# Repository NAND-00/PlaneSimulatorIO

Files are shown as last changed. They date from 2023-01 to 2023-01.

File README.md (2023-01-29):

# PlaneSimulatorIO
Plug'n'play I/O board for connecting flight simulator controls to the PC/MAC via USB with extended X-Plane support.

The I/O board is a USB-HID device designed to connect your flight simulator controls to the flight simulator program. It supports up to 32 digital inputs (buttons or switches), two motorized trims with servo indicators, flaps lever with a servo indicator, fuel quadrant, yoke, pedals and a gear switch with three LED indicators.

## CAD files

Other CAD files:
XPlane_plugin_VSproject/Release/64/Hello-World-SDK-3.obj
XPlane_plugin_VSproject/Release/64/CockpitIOPlugin.obj
XPlane_plugin_VSproject/Release/64/hid.obj

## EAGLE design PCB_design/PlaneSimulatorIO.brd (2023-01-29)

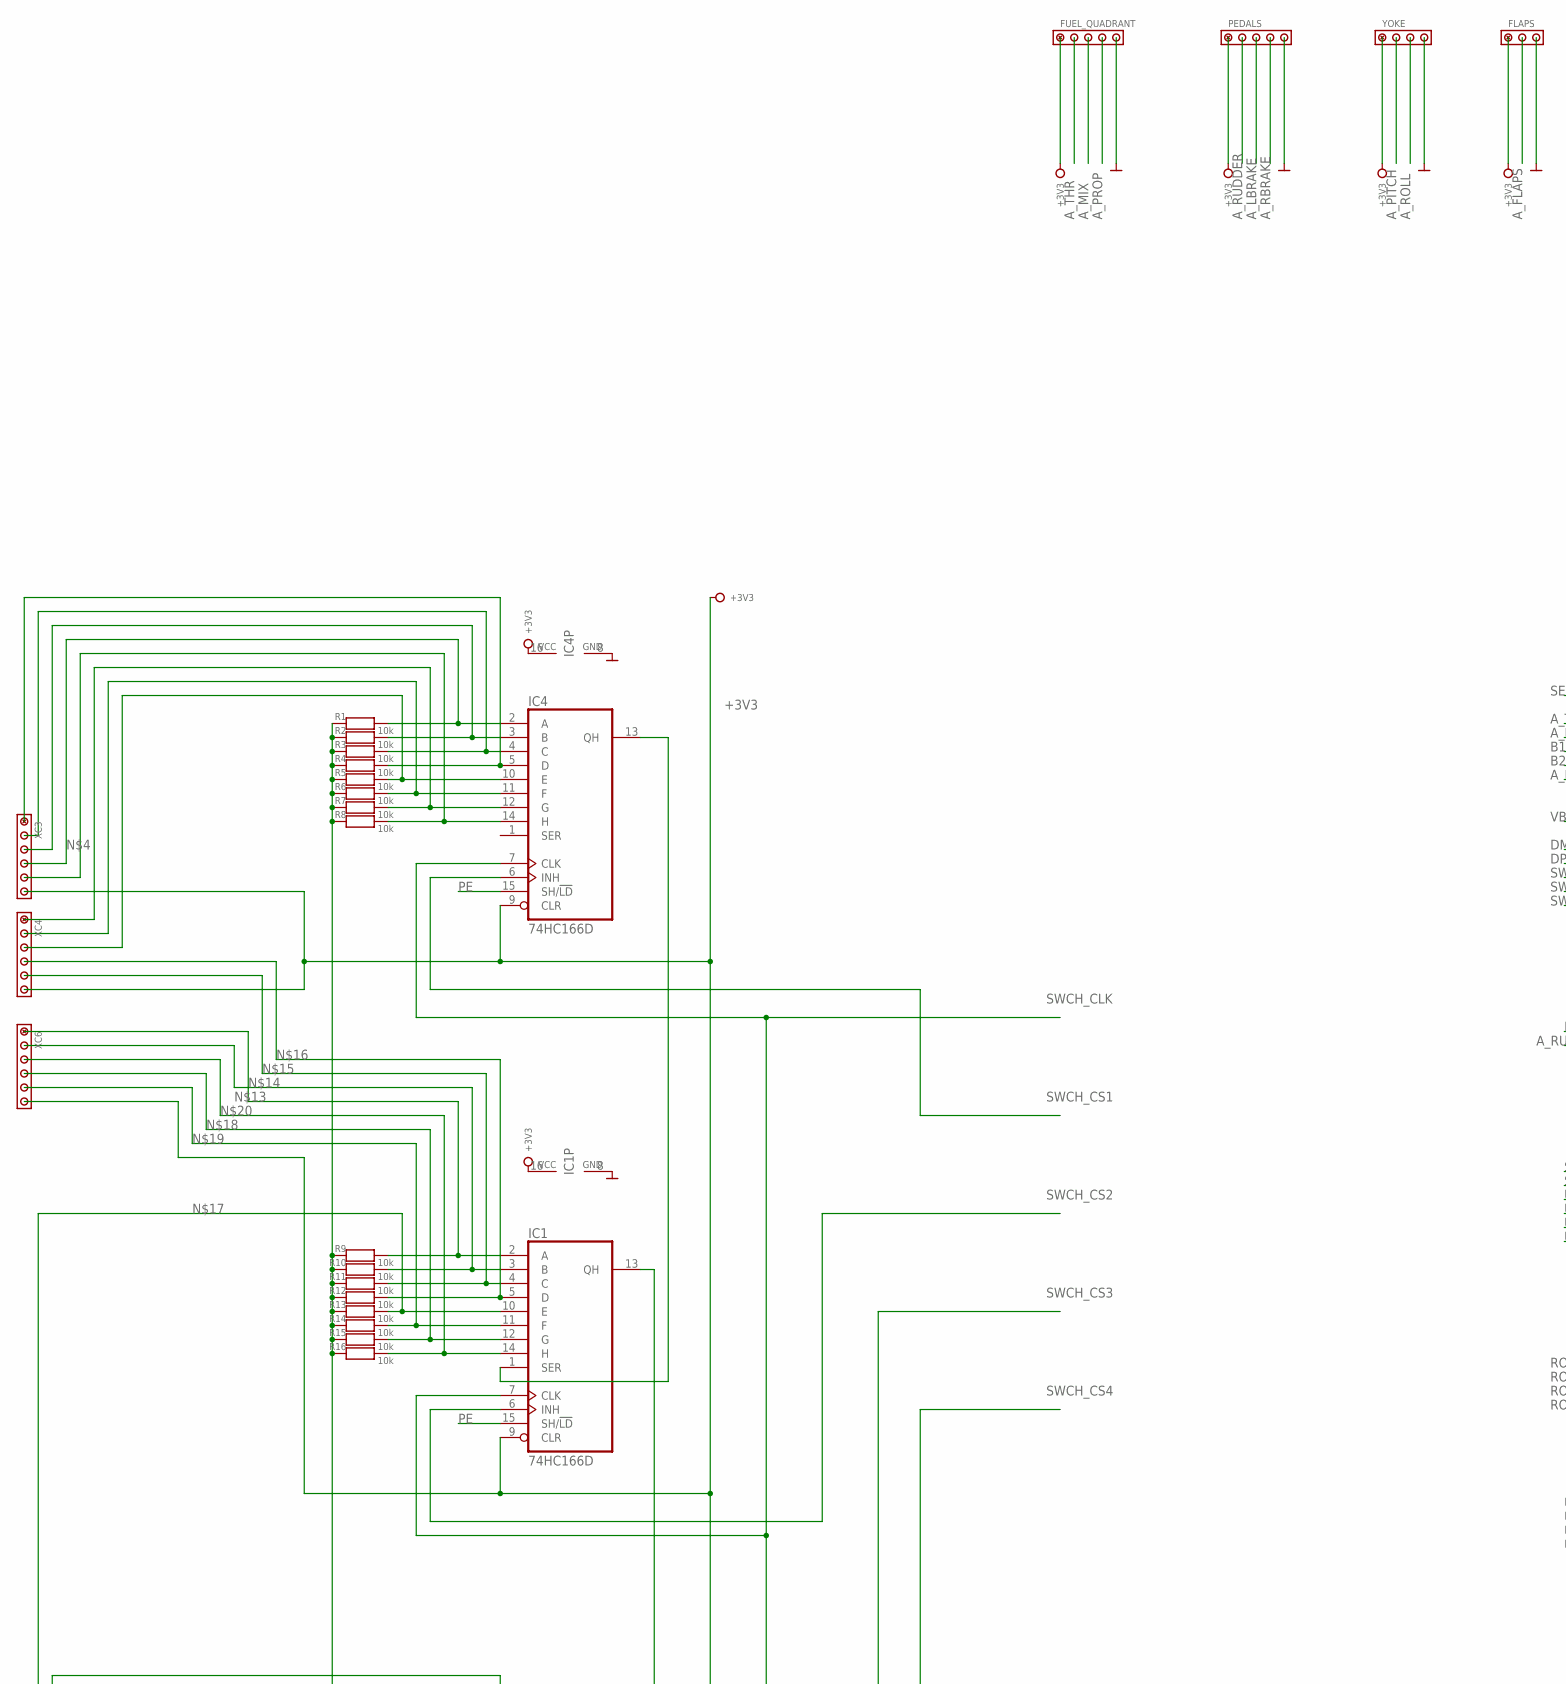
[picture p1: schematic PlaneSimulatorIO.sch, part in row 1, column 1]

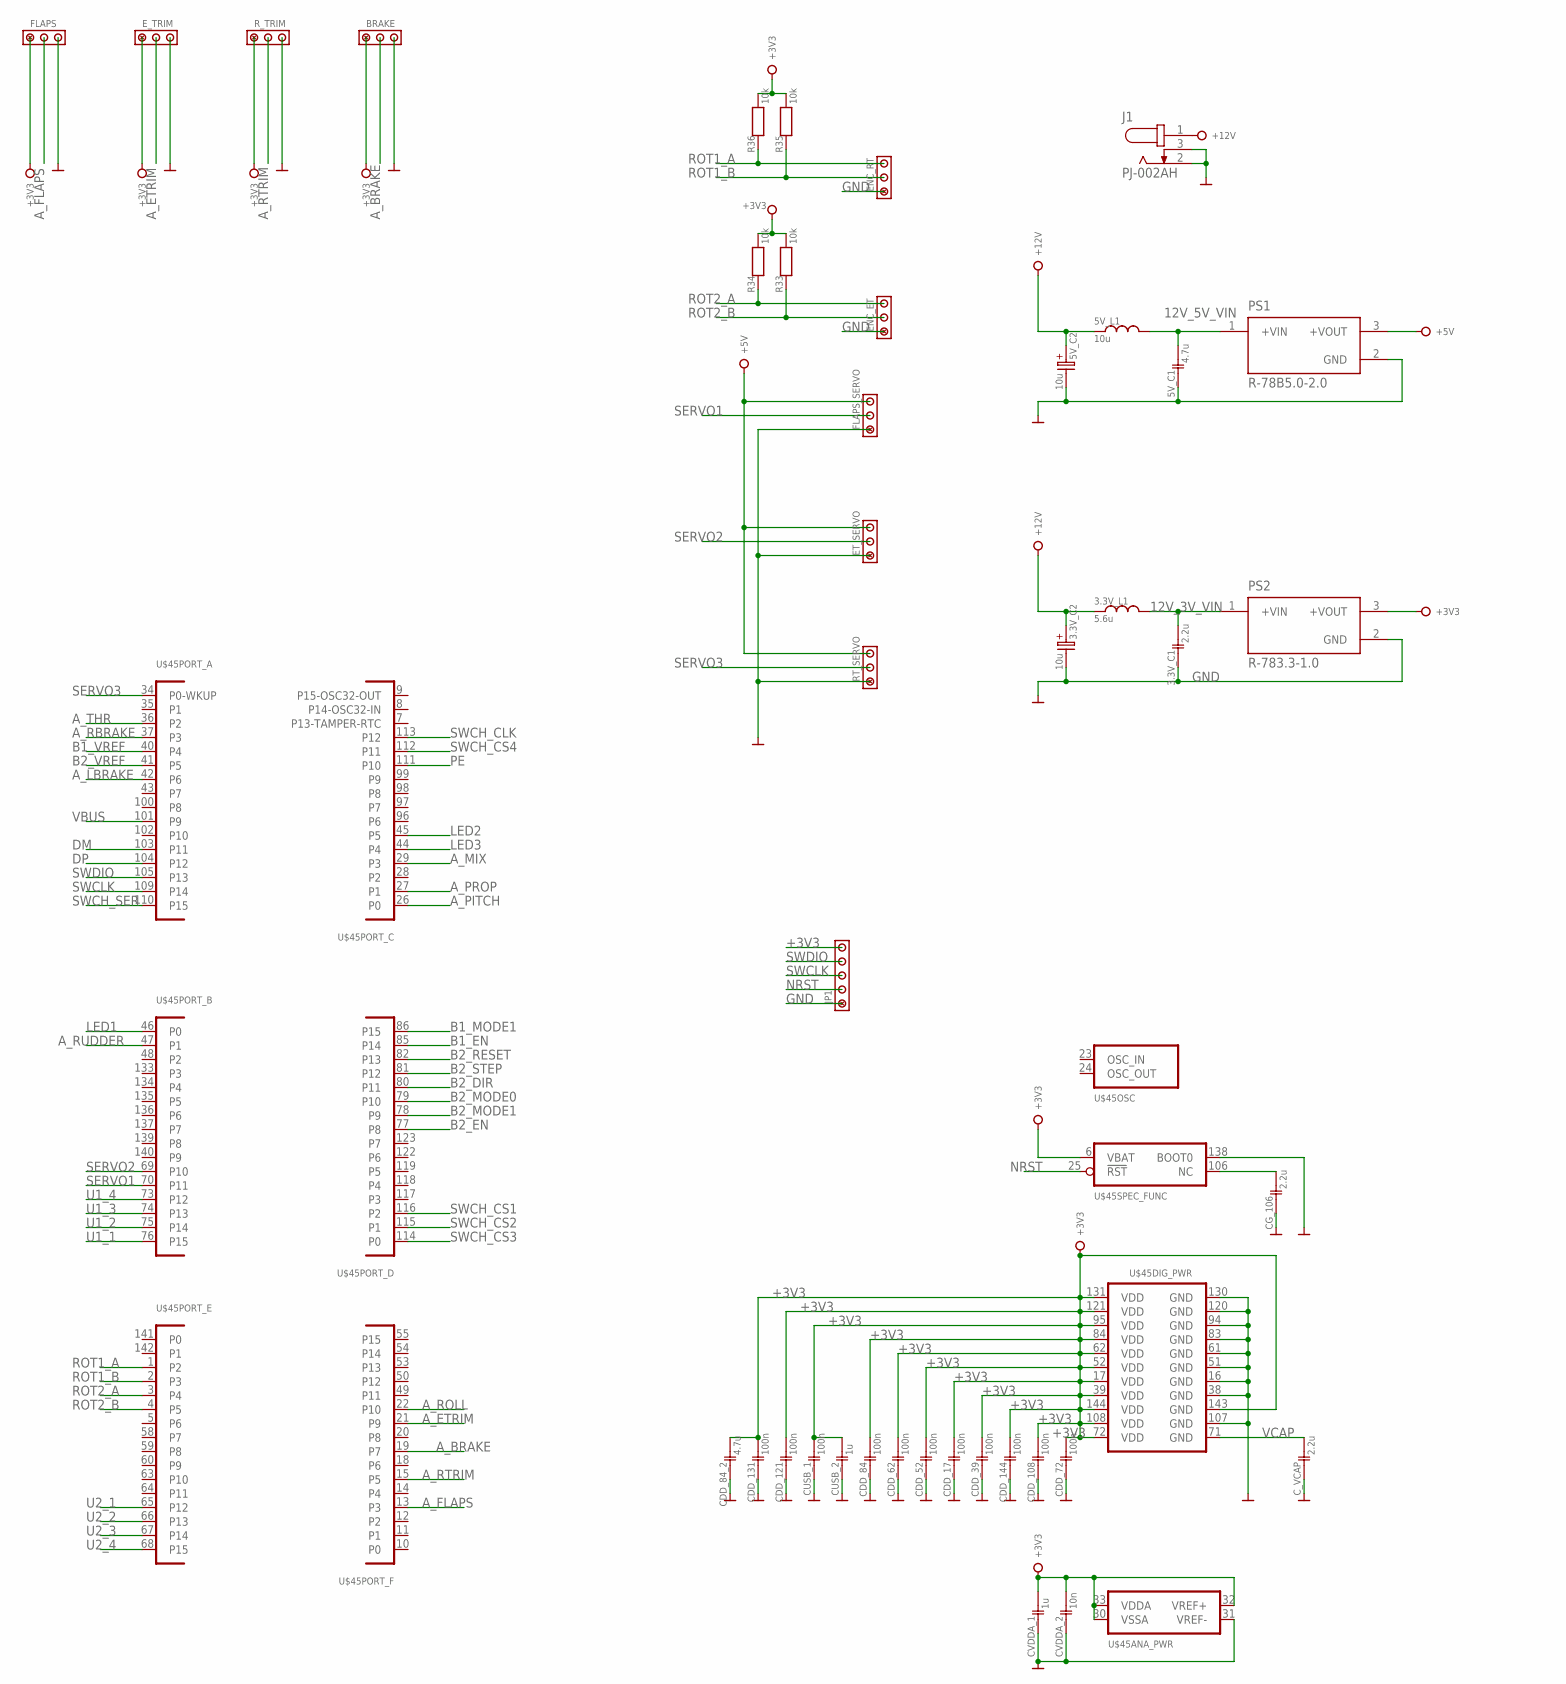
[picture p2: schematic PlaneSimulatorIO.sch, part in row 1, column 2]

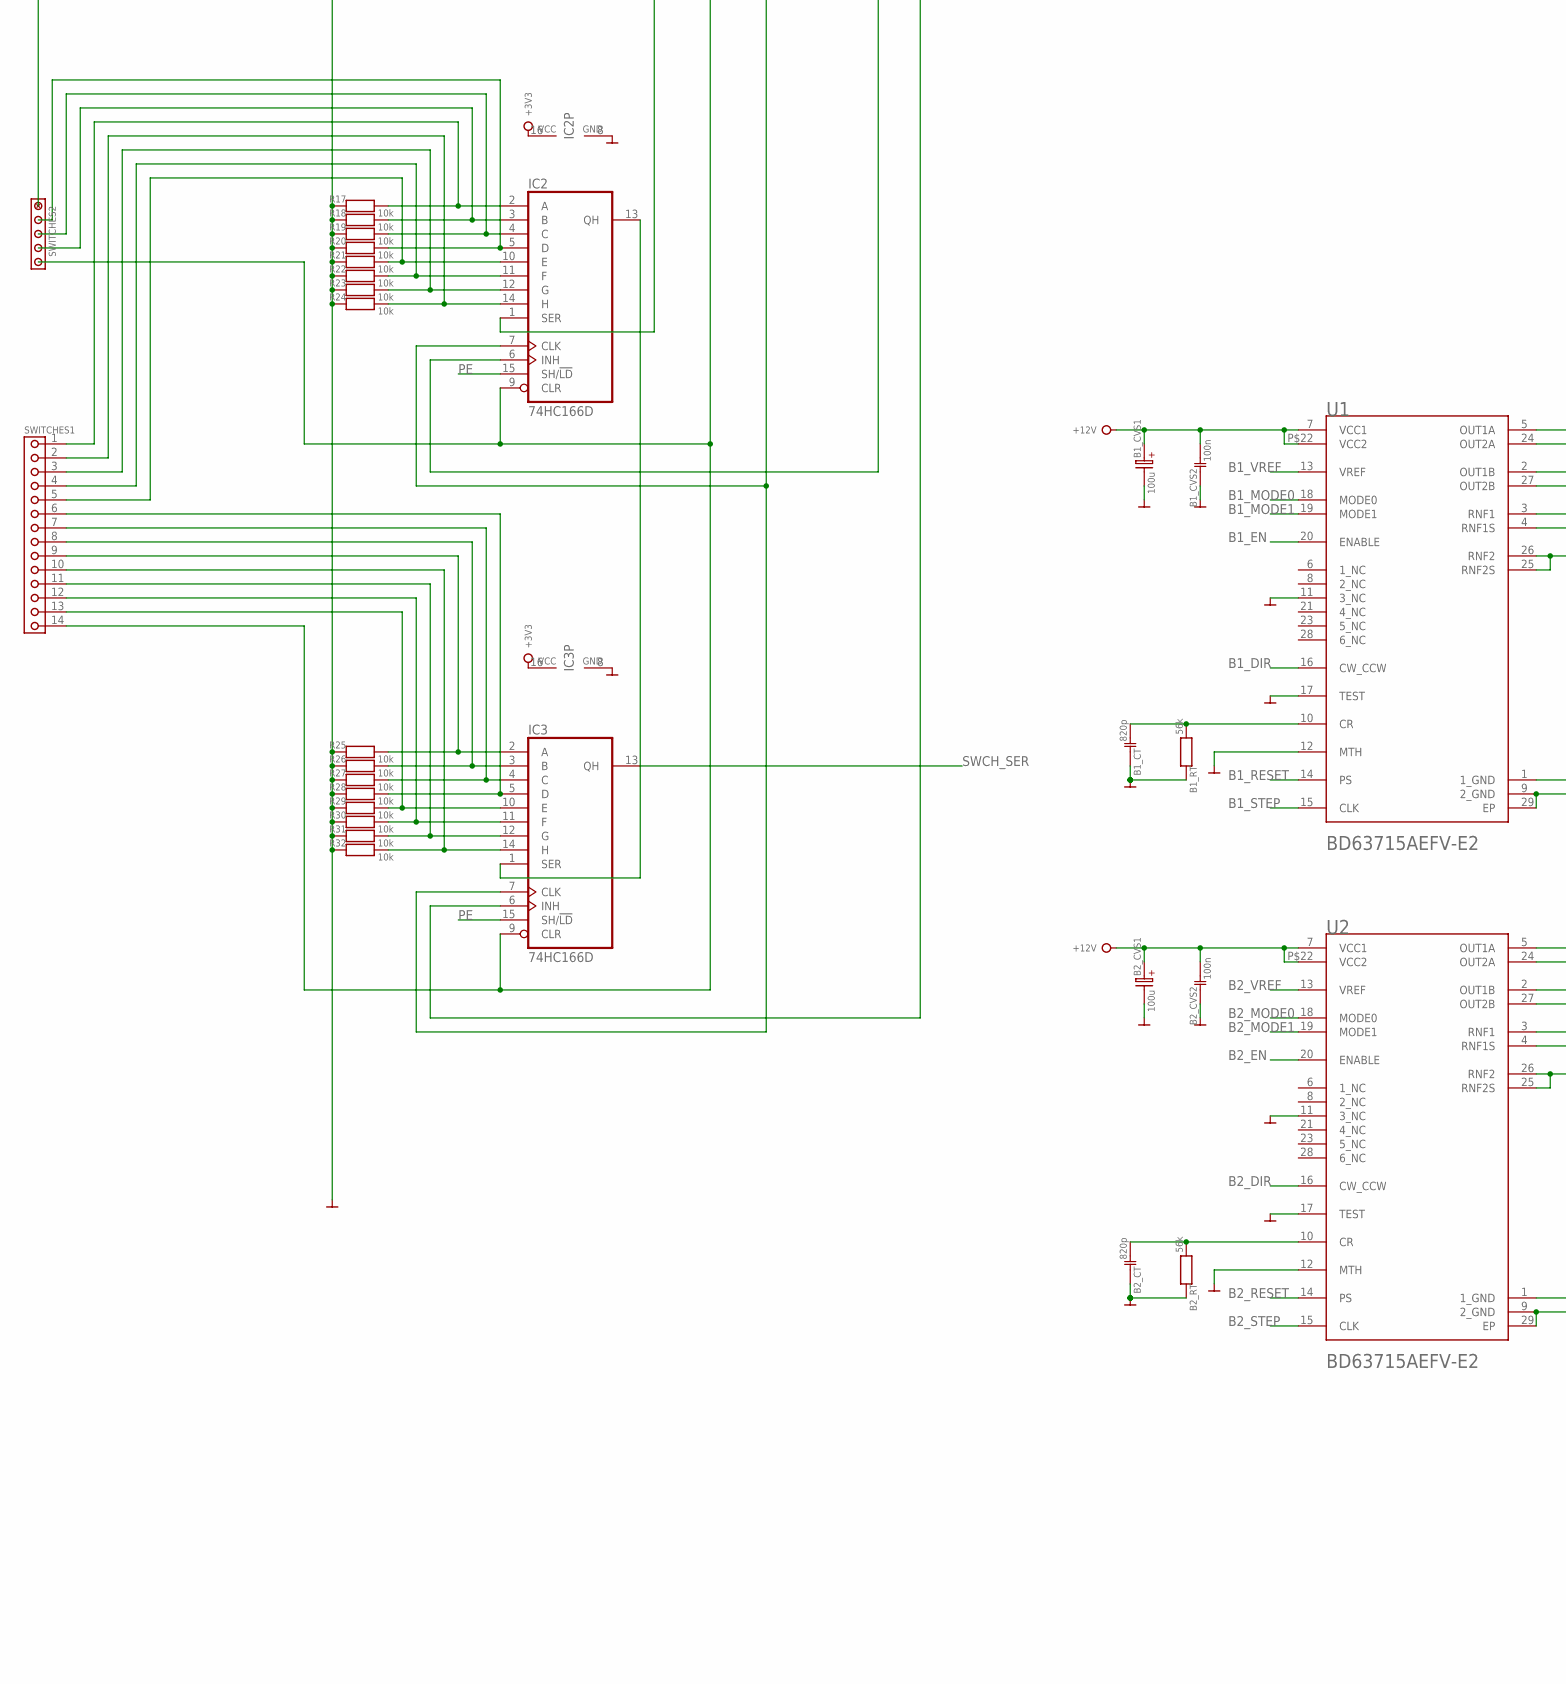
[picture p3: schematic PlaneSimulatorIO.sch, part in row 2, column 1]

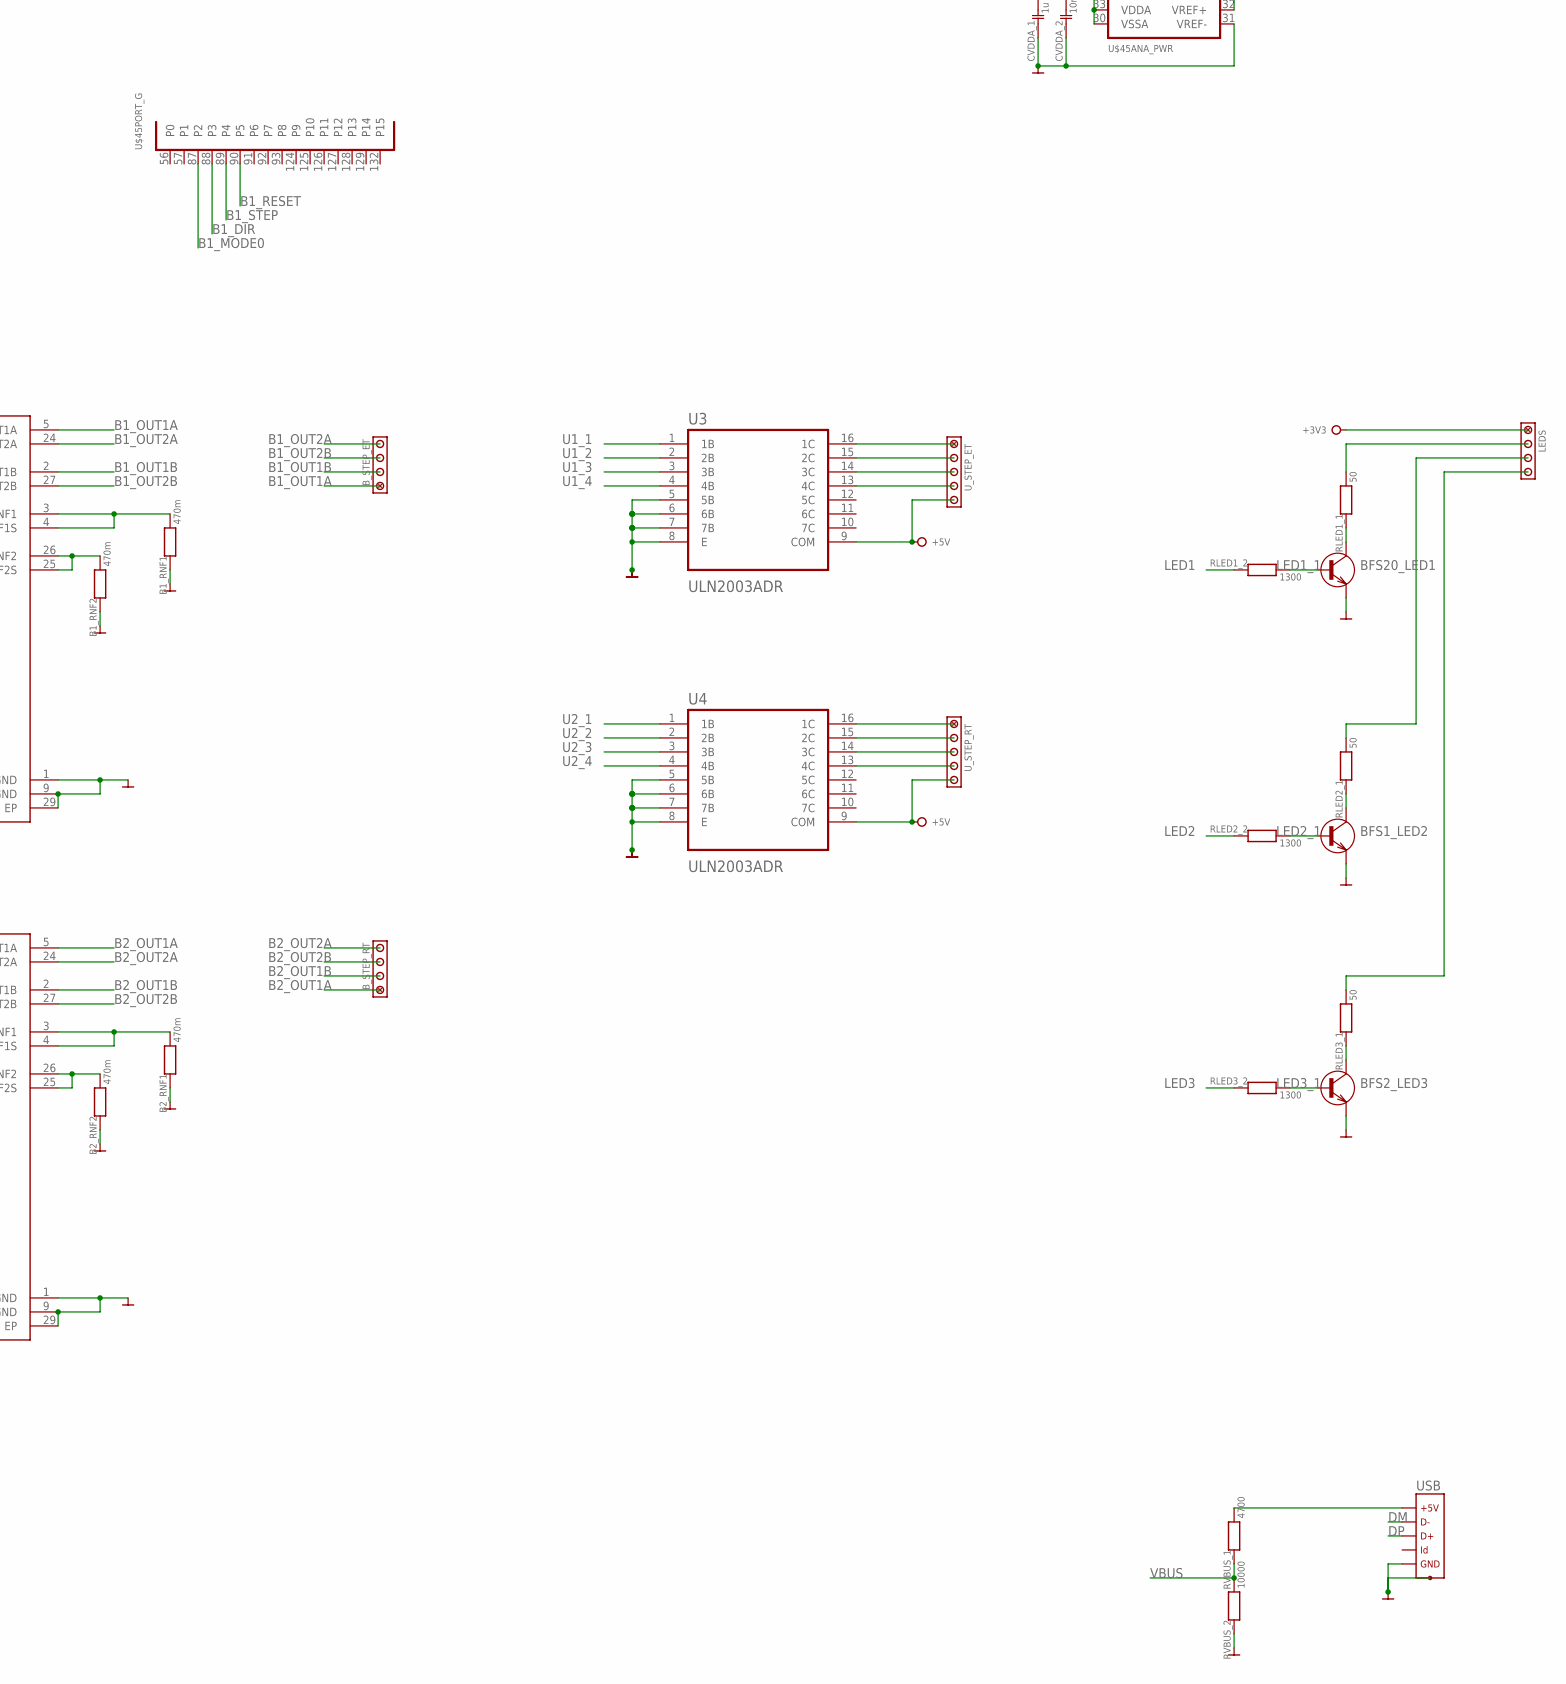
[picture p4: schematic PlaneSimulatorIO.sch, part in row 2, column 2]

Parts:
3.3V_C1: 2.2u; 1206
3.3V_C2, 5V_C2: 10u; EC10-5
3.3V_L1: 5.6u; 0805
5V_C1: 4.7u; 1206
5V_L1: 10u; DR74
B1_CT, B2_CT: 820p; 0603
B1_CVS1, B2_CVS1: 100u; EC10-5
B1_CVS2, B2_CVS2: 100n; 0603
B1_RNF1, B1_RNF2, B2_RNF1, B2_RNF2: 470m; 1206
B1_RT, B2_RT: 56k; 0603
BFS1_LED2, BFS2_LED3, BFS20_LED1: #NPNSOT23-3L; SOT23-3L
BRAKE: MCV/03; MCV3
B_STEP_ET: MCV/04; MCV4
B_STEP_RT: MCV/04; MCV4
CDD_17, CDD_39, CDD_52, CDD_62, CDD_72, CDD_84, CDD_108, CDD_121, CDD_131, CDD_144: 100n; 0603
CDD_84_2: 4.7u; 0603
CG_106: 2.2u; 0603
CUSB_1: 100n; 0603
CUSB_2: 1u; 0603
CVDDA_1: 1u; 0603
CVDDA_2: 10n; 0603
C_VCAP: 2.2u; 0603
ENC_ET: MCV/03; MCV3
ENC_RT: MCV/03; MCV3
ET_SERVO: MCV/03; MCV3
E_TRIM: MCV/03; MCV3
FLAPS: MCV/03; MCV3
FLAPS_SERVO: MCV/03; MCV3
FUEL_QUADRANT: MCV/05; MCV5
IC1, IC2, IC3, IC4: 74HC166D; SO16
J1: PJ-002AH; CUI_PJ-002AH
JP1: JP_05JP_05-2.54; JP_05
LEDS: MCV/04; MCV4
PEDALS: MCV/05; MCV5
PS1: R-78B5.0-2.0; CONV_R-78B5.0-2.0
PS2: R-783.3-1.0; CONV_R-783.3-1.0
R1, R2, R3, R4, R5, R6, R7, R8, R9, R10, R11, R12, R13, R14, R15, R16, R17, R18, R19, R20, R21, R22, R23, R24, R25, R26, R27, R28, R29, R30, R31, R32, R33, R34, R35, R36: 10k; 0603
RLED1_1, RLED2_1, RLED3_1: 50; 0603
RLED1_2, RLED2_2, RLED3_2: 1300; 0603
RT_SERVO: MCV/03; MCV3
RVBUS_1: 4700; 0603
RVBUS_2: 10000; 0603
R_TRIM: MCV/03; MCV3
SWITCHES1: 14MCV3.81; MCV14
SWITCHES2: MCV/05; MCV5
U1, U2: ROHM_BD63715AEFV-E2ROHM_BD63715AEFV-E2_0_3; ROHM_BD63715AEFV-E2_3
U3, U4: ULN2003ADR; SOIC127P600X175-16N
U$45: STM32F103ZE; SQFP-S-20X20-144
USB: USB_5PIN_10118192-0001LF; USB-MICRO-H_10118192-0001LF
U_STEP_ET: MCV/05; MCV5
U_STEP_RT: MCV/05; MCV5
XC3, XC4, XC6: MCV/06; MCV6
YOKE: MCV/04; MCV4

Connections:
12V_3V_VIN: 3.3V_C1.2, 3.3V_L1.2, PS2.1 (+VIN)
12V_5V_VIN: 5V_C1.2, 5V_L1.2, PS1.1 (+VIN)
+3V3: BRAKE.1, CDD_17.2, CDD_39.2, CDD_52.2, CDD_62.2, CDD_72.2, CDD_84.2, CDD_84_2.2, CDD_108.2, CDD_121.2, CDD_131.2, CDD_144.2, CUSB_1.2, CUSB_2.2, CVDDA_1.2, CVDDA_2.2, E_TRIM.1, FLAPS.1, FUEL_QUADRANT.1, IC1.9 (CLR), IC1.16 (VCC), IC2.9 (CLR), IC2.16 (VCC), IC3.9 (CLR), IC3.16 (VCC), IC4.9 (CLR), IC4.16 (VCC), JP1.5, LEDS.1, PEDALS.1, PS2.3 (+VOUT), R33.2, R34.2, R35.2, R36.2, R_TRIM.1, SWITCHES1.14, SWITCHES2.5, U$45.6 (VBAT), U$45.17 (VDD), U$45.30 (VSSA), U$45.32 (VREF+), U$45.33 (VDDA), U$45.39 (VDD), U$45.52 (VDD), U$45.62 (VDD), U$45.72 (VDD), U$45.84 (VDD), U$45.95 (VDD), U$45.108 (VDD), U$45.121 (VDD), U$45.131 (VDD), U$45.143 (GND), U$45.144 (VDD), XC3.6, XC4.6, XC6.6, YOKE.1
+5V: ET_SERVO.3, FLAPS_SERVO.3, PS1.3 (+VOUT), RT_SERVO.3, U3.9 (COM), U4.9 (COM), U_STEP_ET.5, U_STEP_RT.5
+12V: 3.3V_C2.1, 3.3V_L1.1, 5V_C2.1, 5V_L1.1, B1_CVS1.1, B1_CVS2.2, B2_CVS1.1, B2_CVS2.2, J1.1, U1.7 (VCC1), U1.P$22 (VCC2), U2.7 (VCC1), U2.P$22 (VCC2)
A_BRAKE: BRAKE.2, U$45.19 (P7)
A_ETRIM: E_TRIM.2, U$45.21 (P9)
A_FLAPS: FLAPS.2, U$45.13 (P3)
A_LBRAKE: PEDALS.3, U$45.42 (P6)
A_MIX: FUEL_QUADRANT.3, U$45.29 (P3)
A_PITCH: U$45.26 (P0), YOKE.2
A_PROP: FUEL_QUADRANT.4, U$45.27 (P1)
A_RBRAKE: PEDALS.4, U$45.37 (P3)
A_ROLL: U$45.22 (P10), YOKE.3
A_RTRIM: R_TRIM.2, U$45.15 (P5)
A_RUDDER: PEDALS.2, U$45.47 (P1)
A_THR: FUEL_QUADRANT.2, U$45.36 (P2)
B1_DIR: U1.16 (CW_CCW), U$45.88 (P3)
B1_EN: U1.20 (ENABLE), U$45.85 (P14)
B1_MODE0: U1.18 (MODE0), U$45.87 (P2)
B1_MODE1: U1.19 (MODE1), U$45.86 (P15)
B1_OUT1A: B_STEP_ET.1, U1.5 (OUT1A)
B1_OUT1B: B_STEP_ET.2, U1.2 (OUT1B)
B1_OUT2A: B_STEP_ET.4, U1.24 (OUT2A)
B1_OUT2B: B_STEP_ET.3, U1.27 (OUT2B)
B1_RESET: U1.14 (PS), U$45.90 (P5)
B1_STEP: U1.15 (CLK), U$45.89 (P4)
B1_VREF: U1.13 (VREF), U$45.40 (P4)
B2_DIR: U2.16 (CW_CCW), U$45.80 (P11)
B2_EN: U2.20 (ENABLE), U$45.77 (P8)
B2_MODE0: U2.18 (MODE0), U$45.79 (P10)
B2_MODE1: U2.19 (MODE1), U$45.78 (P9)
B2_OUT1A: B_STEP_RT.1, U2.5 (OUT1A)
B2_OUT1B: B_STEP_RT.2, U2.2 (OUT1B)
B2_OUT2A: B_STEP_RT.4, U2.24 (OUT2A)
B2_OUT2B: B_STEP_RT.3, U2.27 (OUT2B)
B2_RESET: U2.14 (PS), U$45.82 (P13)
B2_STEP: U2.15 (CLK), U$45.81 (P12)
B2_VREF: U2.13 (VREF), U$45.41 (P5)
DM: U$45.103 (P11), USB.D- (2)
DP: U$45.104 (P12), USB.D+ (3)
GND: 3.3V_C1.1, 3.3V_C2.2, 5V_C1.1, 5V_C2.2, B1_CT.1, B1_CVS1.2, B1_CVS2.1, B1_RNF1.1, B1_RNF2.1, B1_RT.1, B2_CT.1, B2_CVS1.2, B2_CVS2.1, B2_RNF1.1, B2_RNF2.1, B2_RT.1, BFS1_LED2.2 (E), BFS2_LED3.2 (E), BFS20_LED1.2 (E), BRAKE.3, CDD_17.1, CDD_39.1, CDD_52.1, CDD_62.1, CDD_72.1, CDD_84.1, CDD_84_2.1, CDD_108.1, CDD_121.1, CDD_131.1, CDD_144.1, CG_106.1, CUSB_1.1, CUSB_2.1, CVDDA_1.1, CVDDA_2.1, C_VCAP.1, ENC_ET.1, ENC_RT.1, ET_SERVO.1, E_TRIM.3, FLAPS.3, FLAPS_SERVO.1, FUEL_QUADRANT.5, IC1.8 (GND), IC2.8 (GND), IC3.8 (GND), IC4.8 (GND), J1.2, J1.3, JP1.1, PEDALS.5, PS1.2 (GND), PS2.2 (GND), R1.1, R2.1, R3.1, R4.1, R5.1, R6.1, R7.1, R8.1, R9.1, R10.1, R11.1, R12.1, R13.1, R14.1, R15.1, R16.1, R17.1, R18.1, R19.1, R20.1, R21.1, R22.1, R23.1, R24.1, R25.1, R26.1, R27.1, R28.1, R29.1, R30.1, R31.1, R32.1, RT_SERVO.1, RVBUS_2.1, R_TRIM.3, U1.1 (1_GND), U1.9 (2_GND), U1.11 (3_NC), U1.12 (MTH), U1.17 (TEST), U1.29 (EP), U2.1 (1_GND), U2.9 (2_GND), U2.11 (3_NC), U2.12 (MTH), U2.17 (TEST), U2.29 (EP), U3.5 (5B), U3.6 (6B), U3.7 (7B), U3.8 (E), U4.5 (5B), U4.6 (6B), U4.7 (7B), U4.8 (E), U$45.16 (GND), U$45.31 (VREF-), U$45.38 (GND), U$45.51 (GND), U$45.61 (GND), U$45.83 (GND), U$45.94 (GND), U$45.107 (GND), U$45.120 (GND), U$45.130 (GND), U$45.138 (BOOT0), USB.GND (5), USB.S1 (S), USB.S2 (S), YOKE.4
LED1: RLED1_2.1, U$45.46 (P0)
LED1_1: BFS20_LED1.1 (B), RLED1_2.2
LED2: RLED2_2.1, U$45.45 (P5)
LED2_1: BFS1_LED2.1 (B), RLED2_2.2
LED3: RLED3_2.1, U$45.44 (P4)
LED3_1: BFS2_LED3.1 (B), RLED3_2.2
unnamed: IC4.5 (D), R4.2, XC3.1
unnamed: IC4.4 (C), R3.2, XC3.2
unnamed: IC4.3 (B), R2.2, XC3.3
unnamed: IC4.2 (A), R1.2, XC3.4
unnamed: IC4.10 (E), R5.2, XC4.3
unnamed: IC4.11 (F), R6.2, XC4.2
unnamed: IC4.12 (G), R7.2, XC4.1
unnamed: IC4.14 (H), R8.2, XC3.5
unnamed: U4.16 (1C), U_STEP_RT.1
unnamed: U4.13 (4C), U_STEP_RT.4
unnamed: U4.14 (3C), U_STEP_RT.3
unnamed: IC1.2 (A), R9.2, XC6.1
unnamed: IC1.3 (B), R10.2, XC6.2
unnamed: IC1.4 (C), R11.2, XC4.5
unnamed: IC1.5 (D), R12.2, XC4.4
unnamed: IC1.10 (E), R13.2, SWITCHES2.1
unnamed: IC1.11 (F), R14.2, XC6.5
unnamed: IC1.12 (G), R15.2, XC6.4
unnamed: IC1.14 (H), R16.2, XC6.3
unnamed: U4.15 (2C), U_STEP_RT.2
unnamed: U3.16 (1C), U_STEP_ET.1
unnamed: U3.15 (2C), U_STEP_ET.2
unnamed: IC2.3 (B), R18.2, SWITCHES2.4
unnamed: IC2.4 (C), R19.2, SWITCHES2.3
unnamed: IC2.5 (D), R20.2, SWITCHES2.2
unnamed: IC2.2 (A), R17.2, SWITCHES1.1
unnamed: IC2.14 (H), R24.2, SWITCHES1.2
unnamed: IC2.12 (G), R23.2, SWITCHES1.3
unnamed: IC2.11 (F), R22.2, SWITCHES1.4
unnamed: IC2.10 (E), R21.2, SWITCHES1.5
unnamed: U3.14 (3C), U_STEP_ET.3
unnamed: U3.13 (4C), U_STEP_ET.4
unnamed: B2_CT.2, B2_RT.2, U2.10 (CR)
unnamed: B2_RNF1.2, U2.3 (RNF1), U2.4 (RNF1S)
unnamed: IC3.5 (D), R28.2, SWITCHES1.6
unnamed: IC3.4 (C), R27.2, SWITCHES1.7
unnamed: IC3.3 (B), R26.2, SWITCHES1.8
unnamed: IC3.2 (A), R25.2, SWITCHES1.9
unnamed: IC3.14 (H), R32.2, SWITCHES1.10
unnamed: IC3.12 (G), R31.2, SWITCHES1.11
unnamed: IC3.11 (F), R30.2, SWITCHES1.12
unnamed: B2_RNF2.2, U2.25 (RNF2S), U2.26 (RNF2)
unnamed: IC3.10 (E), R29.2, SWITCHES1.13
unnamed: CG_106.2, U$45.106 (NC)
unnamed: BFS1_LED2.3 (C), RLED2_1.1
unnamed: IC2.13 (QH), IC3.1 (SER)
unnamed: IC1.13 (QH), IC2.1 (SER)
unnamed: IC1.1 (SER), IC4.13 (QH)
unnamed: B1_RNF1.2, U1.3 (RNF1), U1.4 (RNF1S)
unnamed: B1_CT.2, B1_RT.2, U1.10 (CR)
unnamed: B1_RNF2.2, U1.25 (RNF2S), U1.26 (RNF2)
unnamed: RVBUS_1.2, USB.VBUS (1)
unnamed: BFS20_LED1.3 (C), RLED1_1.1
unnamed: LEDS.2, RLED1_1.2
unnamed: LEDS.3, RLED2_1.2
unnamed: BFS2_LED3.3 (C), RLED3_1.1
unnamed: LEDS.4, RLED3_1.2
NRST: JP1.2, U$45.25 (!RST)
PE: IC1.15 (SH/!LD), IC2.15 (SH/!LD), IC3.15 (SH/!LD), IC4.15 (SH/!LD), U$45.111 (P10)
ROT1_A: ENC_RT.3, R36.1, U$45.1 (P2)
ROT1_B: ENC_RT.2, R35.1, U$45.2 (P3)
ROT2_A: ENC_ET.3, R34.1, U$45.3 (P4)
ROT2_B: ENC_ET.2, R33.1, U$45.4 (P5)
SERVO1: FLAPS_SERVO.2, U$45.70 (P11)
SERVO2: ET_SERVO.2, U$45.69 (P10)
SERVO3: RT_SERVO.2, U$45.34 (P0-WKUP)
SWCH_CLK: IC1.7 (CLK), IC2.7 (CLK), IC3.7 (CLK), IC4.7 (CLK), U$45.113 (P12)
SWCH_CS1: IC4.6 (INH), U$45.116 (P2)
SWCH_CS2: IC1.6 (INH), U$45.115 (P1)
SWCH_CS3: IC2.6 (INH), U$45.114 (P0)
SWCH_CS4: IC3.6 (INH), U$45.112 (P11)
SWCH_SER: IC3.13 (QH), U$45.110 (P15)
SWCLK: JP1.3, U$45.109 (P14)
SWDIO: JP1.4, U$45.105 (P13)
U1_1: U3.1 (1B), U$45.76 (P15)
U1_2: U3.2 (2B), U$45.75 (P14)
U1_3: U3.3 (3B), U$45.74 (P13)
U1_4: U3.4 (4B), U$45.73 (P12)
U2_1: U4.1 (1B), U$45.65 (P12)
U2_2: U4.2 (2B), U$45.66 (P13)
U2_3: U4.3 (3B), U$45.67 (P14)
U2_4: U4.4 (4B), U$45.68 (P15)
VBUS: RVBUS_1.1, RVBUS_2.2, U$45.101 (P9)
VCAP: C_VCAP.2, U$45.71 (GND)

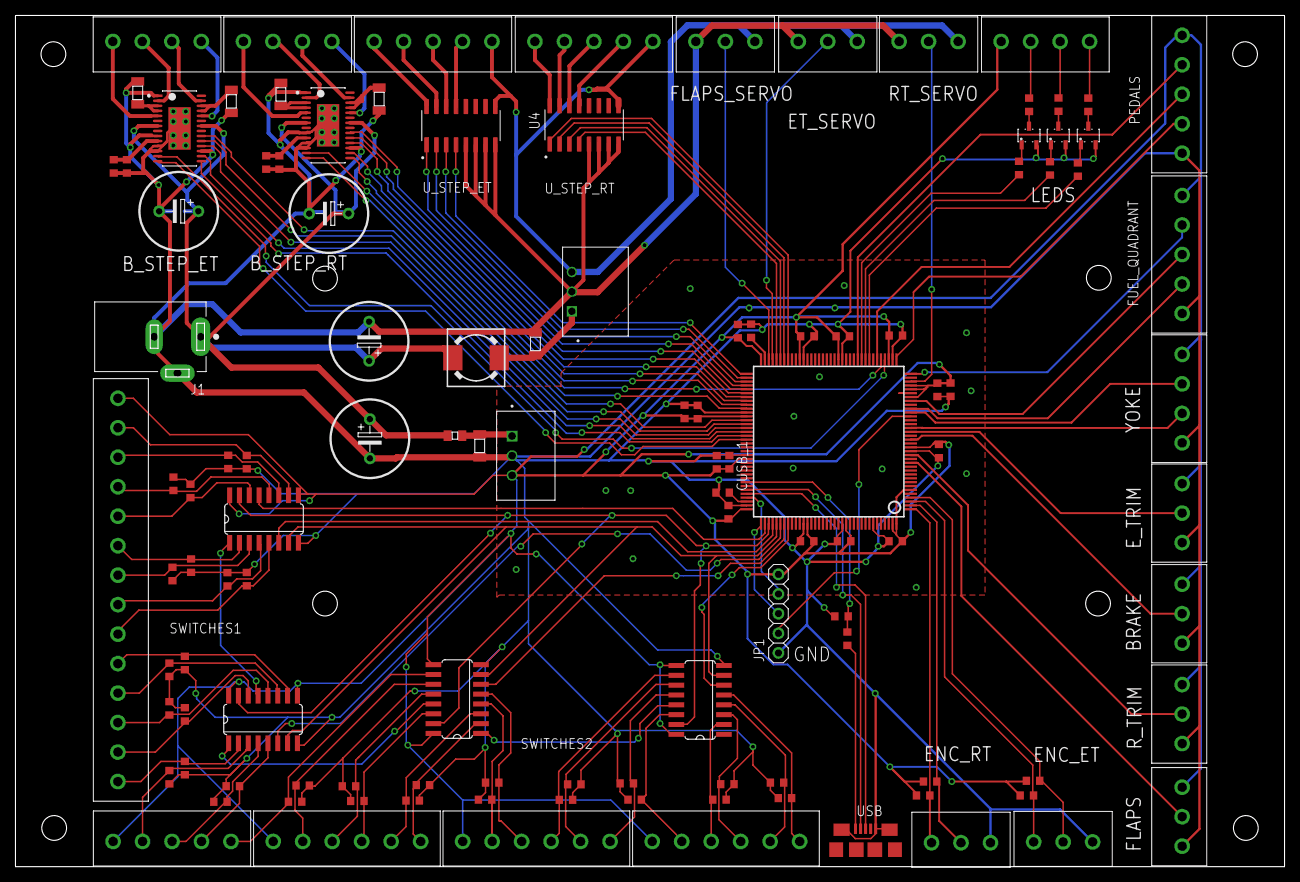
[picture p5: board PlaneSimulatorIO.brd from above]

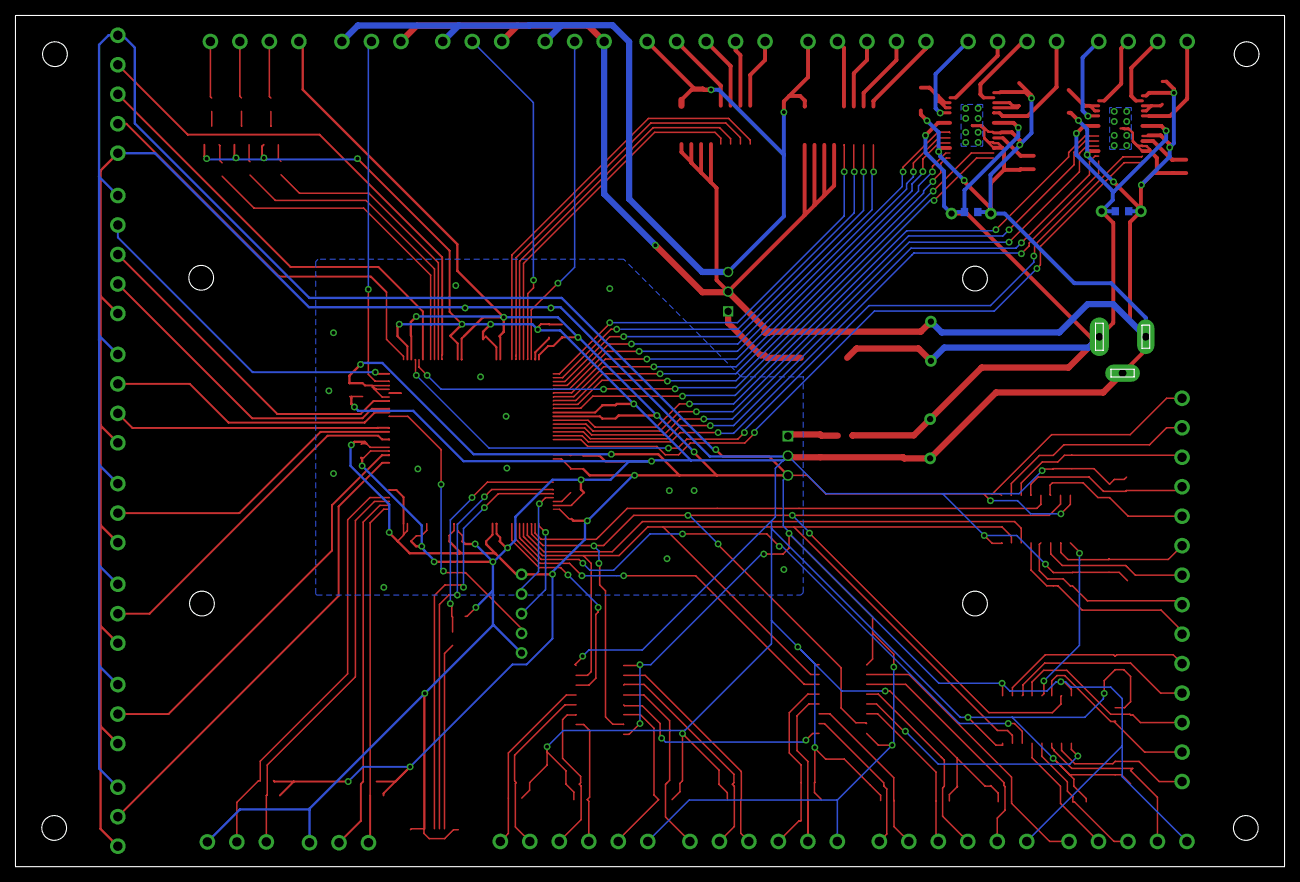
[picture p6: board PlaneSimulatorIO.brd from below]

Board: 2 copper layers, 164.0 x 110.0 mm, 126 parts (2 on the bottom side), 132 nets.

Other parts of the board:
U$1, U$2, U$3, U$4, U$5, U$43, U$44, U$62: M3-HOLE

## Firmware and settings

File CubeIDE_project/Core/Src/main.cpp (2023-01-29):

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
/* Includes ------------------------------------------------------------------*/
#include "main.h"
#include "string.h"
#include "usb_device.h"

/* USER CODE BEGIN Includes */
#include "data.hpp"
#include "usbd_hid.h"
#include <vector>
#include <string>
#include <iomanip>
#include <stdint.h>
#include <memory>
#include <bitset>
#include <any>
/* USER CODE END Includes */

ADC_HandleTypeDef hadc2;
ADC_HandleTypeDef hadc3;

DAC_HandleTypeDef hdac1;

TIM_HandleTypeDef htim2;
TIM_HandleTypeDef htim3;

/* USER CODE BEGIN PV */
bipolarMotor b_motor1(GPIOG, GPIO_PIN_4, GPIOG, GPIO_PIN_3, GPIOD, GPIO_PIN_14, GPIOG, GPIO_PIN_5, GPIOG, GPIO_PIN_2, GPIOD, GPIO_PIN_15, DAC_CHANNEL_1);
unipolarMotor u_motor1(GPIOB, GPIO_PIN_15, GPIOB, GPIO_PIN_14, GPIOB,GPIO_PIN_13, GPIOB, GPIO_PIN_12);
bipolarMotor b_motor2(GPIOD, GPIO_PIN_12, GPIOD, GPIO_PIN_11, GPIOD, GPIO_PIN_8, GPIOD, GPIO_PIN_13, GPIOD, GPIO_PIN_10, GPIOD, GPIO_PIN_9, DAC_CHANNEL_2);
unipolarMotor u_motor2(GPIOE, GPIO_PIN_12, GPIOE, GPIO_PIN_13, GPIOE,GPIO_PIN_14, GPIOE, GPIO_PIN_15);

extern uint8_t IN_Buffer[HID_IN_BUFFER_SIZE];
extern vector<unique_ptr<Device> > allDevices;
extern USBD_HandleTypeDef hUsbDeviceHS;
extern int readyToMoveStepper;
/* USER CODE END PV */

void SystemClock_Config(void);
void PeriphCommonClock_Config(void);
static void MX_GPIO_Init(void);
static void MX_ADC2_Init(void);
static void MX_ADC3_Init(void);
static void MX_DAC1_Init(void);
static void MX_TIM2_Init(void);
static void MX_TIM3_Init(void);
/**
  * @brief  The application entry point.
  * @retval int
  */
int main(void)
{
  /* MCU Configuration--------------------------------------------------------*/

  /* Reset of all peripherals, Initializes the Flash interface and the Systick. */
  HAL_Init();

  /* Configure the system clock */
  SystemClock_Config();

/* Configure the peripherals common clocks */
  PeriphCommonClock_Config();

  /* Initialize all configured peripherals */
  MX_GPIO_Init();
  MX_ADC2_Init();
  MX_ADC3_Init();
  MX_DAC1_Init();
  MX_TIM2_Init();
  MX_USB_DEVICE_Init();
  MX_TIM3_Init();
  HAL_TIM_Base_Start_IT(&htim3);

  /* USER CODE BEGIN 2 */
  HAL_TIM_PWM_Start(&htim2, TIM_CHANNEL_1);
  HAL_TIM_PWM_Start(&htim2, TIM_CHANNEL_3);
  HAL_TIM_PWM_Start(&htim2, TIM_CHANNEL_4);
  readyToMoveStepper = 0;
  HAL_DAC_Start(&hdac1, DAC_CHANNEL_1);
  HAL_DAC_Start(&hdac1, DAC_CHANNEL_2);

  activateDevices(allDevices);
  HAL_StatusTypeDef ret = HAL_ADCEx_Calibration_Start(&hadc2, ADC_CALIB_OFFSET, ADC_SINGLE_ENDED);
    if (ret != HAL_OK)
    	  {
    	    Error_Handler();
    	  }
    ret = HAL_ADCEx_Calibration_Start(&hadc3, ADC_CALIB_OFFSET, ADC_SINGLE_ENDED);
        if (ret != HAL_OK)
        	  {
        	    Error_Handler();
        	  }

  /* USER CODE END 2 */

  /* Infinite loop */
  /* USER CODE BEGIN WHILE */
  while (1)
  {
	  int bufferPosition = 0;

		  for(unsigned int i = 0; i<allDevices.size(); i++){
			  allDevices[i]->readData();
			  allDevices[i]->updateDeviceState();
			  allDevices[i]->updateDeviceBuffer();
			  allDevices[i]->returnDeviceBuffer(IN_Buffer, bufferPosition);
			  bufferPosition += allDevices[i]->returnDeviceBufferSize();
		  }

		  USBD_HID_SendReport(&hUsbDeviceHS,IN_Buffer,HID_IN_BUFFER_SIZE);

		  if(readyToMoveStepper == 1){
		  		 readyToMoveStepper = 0;
		  		b_motor1.moveIfRequested();
		  		u_motor1.moveIfRequested();
		  		b_motor2.moveIfRequested();
				u_motor2.moveIfRequested();
		  	  }
    /* USER CODE END WHILE */

    /* USER CODE BEGIN 3 */
  }
  /* USER CODE END 3 */
}

void HAL_TIM_PeriodElapsedCallback(TIM_HandleTypeDef* htim)
{
	readyToMoveStepper = 1;

}
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


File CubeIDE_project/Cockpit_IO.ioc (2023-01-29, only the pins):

Mcu.UserName=STM32H723ZGTx
PA0.Signal=S_TIM2_CH1
PA11.Signal=USB_OTG_HS_DM
PA12.Signal=USB_OTG_HS_DP
PA15(JTDI).Signal=GPIO_Input
PA2.Signal=ADCx_INP14
PA3.Signal=ADCx_INP15
PA4.Signal=COMP_DAC11_group
PA5.Signal=COMP_DAC12_group
PA6.Signal=ADCx_INP3
PB0.Signal=GPIO_Output
PB1.Signal=ADCx_INP5
PB10.Signal=S_TIM2_CH3
PB11.Signal=S_TIM2_CH4
PB12.Signal=GPIO_Output
PB13.Signal=GPIO_Output
PB14.Signal=GPIO_Output
PB15.Signal=GPIO_Output
PC0.Signal=ADCx_INP10
PC1.Signal=ADCx_INP11
PC10.Signal=GPIO_Output
PC11.Signal=GPIO_Output
PC12.Signal=GPIO_Output
PC3_C.Signal=ADC3_INP1
PC4.Signal=GPIO_Output
PC5.Signal=GPIO_Output
PD10.Signal=GPIO_Output
PD11.Signal=GPIO_Output
PD12.Signal=GPIO_Output
PD13.Signal=GPIO_Output
PD14.Signal=GPIO_Output
PD15.Signal=GPIO_Output
PD8.Signal=GPIO_Output
PD9.Signal=GPIO_Output
PE12.Signal=GPIO_Output
PE13.Signal=GPIO_Output
PE14.Signal=GPIO_Output
PE15.Signal=GPIO_Output
PE2.Signal=GPIO_Input
PE3.Signal=GPIO_Input
PE4.Signal=GPIO_Input
PE5.Signal=GPIO_Input
PF10.Signal=ADC3_INP6
PF3.Signal=ADC3_INP5
PF5.Signal=ADC3_INP4
PF7.Signal=ADC3_INP3
PF9.Signal=ADC3_INP2
PG2.Signal=GPIO_Output
PG3.Signal=GPIO_Output
PG4.Signal=GPIO_Output
PG5.Signal=GPIO_Output

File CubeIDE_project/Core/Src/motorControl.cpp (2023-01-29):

#include "motorControl.hpp"



void unipolarMotor::moveOneStep(){
	if(motorState == MOTOR_ENABLED){
		HAL_GPIO_WritePin(pinPorts[0], controlPins[0], unipolarStepPattern[motorPhase][0]);
		HAL_GPIO_WritePin(pinPorts[1], controlPins[1], unipolarStepPattern[motorPhase][1]);
		HAL_GPIO_WritePin(pinPorts[2], controlPins[2], unipolarStepPattern[motorPhase][2]);
		HAL_GPIO_WritePin(pinPorts[3], controlPins[3], unipolarStepPattern[motorPhase][3]);

		if(currentDir == DIR_CCW){

			if(motorPhase == LAST_PHASE){
				motorPhase = FIRST_PHASE;
			}
			else{
				motorPhase++;
			}
		}
		else if(currentDir == DIR_CW){
			if(motorPhase == FIRST_PHASE){
					motorPhase = LAST_PHASE;
				}
			else{
				motorPhase--;
			}
		}
	}
}

void unipolarMotor::moveIfRequested(){
	if(stepsToMove > 0 && motorState == MOTOR_ENABLED){
		moveOneStep();
		stepsToMove--;
	}
}

void unipolarMotor::addSteps(int steps, uint8_t direction){
	if(direction == currentDir){
		stepsToMove += steps;
	}
	else{
		stepsToMove = steps;
		currentDir = direction;
	}
}

void unipolarMotor::setSteps(int steps, uint8_t direction){
	stepsToMove = steps;
	currentDir = direction;
}

void unipolarMotor::turnOff(){
	motorState = MOTOR_DISABLED;
	HAL_GPIO_WritePin(pinPorts[0], controlPins[0], GPIO_PIN_RESET);
	HAL_GPIO_WritePin(pinPorts[1], controlPins[1], GPIO_PIN_RESET);
	HAL_GPIO_WritePin(pinPorts[2], controlPins[2], GPIO_PIN_RESET);
	HAL_GPIO_WritePin(pinPorts[3], controlPins[3], GPIO_PIN_RESET);
}

void unipolarMotor::turnOn(){
	motorState = MOTOR_ENABLED;
}

void bipolarMotor::moveOneStep(){

	if(motorState == MOTOR_ENABLED){
		if(currentDir == DIR_CW){
			HAL_GPIO_WritePin(pinPorts[1],  controlPins[1], GPIO_PIN_SET);
		}
		else if(currentDir == DIR_CCW){
			HAL_GPIO_WritePin(pinPorts[1],  controlPins[1], GPIO_PIN_RESET);
		}
		HAL_GPIO_WritePin(pinPorts[0],  controlPins[0], GPIO_PIN_SET);
		HAL_GPIO_WritePin(pinPorts[0],  controlPins[0], GPIO_PIN_RESET);
	}
}

void bipolarMotor::moveIfRequested(){

	if(stepsToMove > 0 && motorState == MOTOR_ENABLED){
		moveOneStep();
		stepsToMove--;
	}
}

void bipolarMotor::addSteps(int steps, uint8_t direction){
	if(direction == currentDir){
		stepsToMove += steps;
	}
	else{
		stepsToMove = steps;
		currentDir = direction;
	}
}

void bipolarMotor::setSteps(int steps, uint8_t direction){
	stepsToMove = steps;
	currentDir = direction;
}

void bipolarMotor::turnOff(){
	motorState = MOTOR_DISABLED;
	HAL_GPIO_WritePin(pinPorts[2],  controlPins[2], GPIO_PIN_RESET);
}

void bipolarMotor::turnOn(){
	motorState = MOTOR_ENABLED;
	HAL_GPIO_WritePin(pinPorts[2],  controlPins[2], GPIO_PIN_SET);
	HAL_GPIO_WritePin(pinPorts[3],  controlPins[3], GPIO_PIN_SET);
	int dacValue = (int)(4.095 *(float)outputCurrent);
	HAL_DAC_SetValue(&hdac1, dacChannel, DAC_ALIGN_12B_R, dacValue);
}

void bipolarMotor::setOutputCurrent(uint16_t current){
	outputCurrent = current;
	int dacValue = (int)(4.095 *(float)outputCurrent);
	HAL_DAC_SetValue(&hdac1, dacChannel, DAC_ALIGN_12B_R, dacValue);
	HAL_GPIO_TogglePin(GPIOE, GPIO_PIN_1);//test
}

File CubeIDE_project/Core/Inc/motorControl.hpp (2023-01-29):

#include "stm32h7xx.h"
#include <stdint.h>

#define DIR_CW 1
#define DIR_CCW 0
#define MOTOR_DISABLED 0
#define MOTOR_ENABLED 1
#define FIRST_PHASE 0
#define LAST_PHASE 3

extern DAC_HandleTypeDef hdac1;

static GPIO_PinState unipolarStepPattern[4][4] = {
		{GPIO_PIN_SET, GPIO_PIN_RESET, GPIO_PIN_RESET, GPIO_PIN_SET},
		{GPIO_PIN_RESET, GPIO_PIN_RESET, GPIO_PIN_SET, GPIO_PIN_SET},
		{GPIO_PIN_RESET, GPIO_PIN_SET, GPIO_PIN_SET, GPIO_PIN_RESET},
		{GPIO_PIN_SET, GPIO_PIN_SET, GPIO_PIN_RESET, GPIO_PIN_RESET}
};

class unipolarMotor{
protected:
	GPIO_TypeDef * pinPorts[4];
	uint16_t controlPins[4];

	uint8_t currentDir;
	uint8_t stepsToMove;
	uint8_t motorState;
	uint8_t motorPhase;
public:
	void moveOneStep();
	void moveIfRequested();
	void addSteps(int steps, uint8_t direction);
	void setSteps(int steps, uint8_t direction);
	void turnOff();
	void turnOn();

unipolarMotor(GPIO_TypeDef * firstPort, uint16_t firstPin, GPIO_TypeDef * secondPort, uint16_t secondPin, GPIO_TypeDef * thirdPort, uint16_t thirdPin, GPIO_TypeDef * fourthPort, uint16_t fourthPin){
		pinPorts[0] = firstPort;
		pinPorts[1] = secondPort;
		pinPorts[2] = thirdPort;
		pinPorts[3] = fourthPort;

		controlPins[0] = firstPin;
		controlPins[1] = secondPin;
		controlPins[2] = thirdPin;
		controlPins[3] = fourthPin;

		motorState = MOTOR_DISABLED;
		motorPhase = FIRST_PHASE;
		currentDir = DIR_CW;
		stepsToMove = 0;
	};
};

class bipolarMotor{
protected:
	GPIO_TypeDef * pinPorts[6];
	uint16_t controlPins[6];
	uint8_t dacChannel;

	uint8_t currentDir;
	uint8_t stepsToMove;
	uint8_t motorState;
	uint16_t outputCurrent;
public:
	void moveOneStep();
	void moveIfRequested();
	void addSteps(int steps, uint8_t direction);
	void setSteps(int steps, uint8_t direction);
	void turnOff();
	void turnOn();
	void setOutputCurrent(uint16_t current);
	bipolarMotor(GPIO_TypeDef * firstPort, uint16_t firstPin, GPIO_TypeDef * secondPort, uint16_t secondPin, GPIO_TypeDef * thirdPort, uint16_t thirdPin, GPIO_TypeDef * fourthPort, uint16_t fourthPin, GPIO_TypeDef * fifthPort, uint16_t fifthPin, GPIO_TypeDef * sixthPort, uint16_t sixthPin, uint8_t dacCh){
		pinPorts[0] = firstPort;
		pinPorts[1] = secondPort;
		pinPorts[2] = thirdPort;
		pinPorts[3] = fourthPort;
		pinPorts[4] = fifthPort;
		pinPorts[5] = sixthPort;

		controlPins[0] = firstPin; //step
		controlPins[1] = secondPin; //dir
		controlPins[2] = thirdPin; //enable
		controlPins[3] = fourthPin; //reset
		controlPins[4] = fifthPin; //mode0
		controlPins[5] = sixthPin; //mode1

		dacChannel = dacCh;
		motorState = MOTOR_DISABLED;
		currentDir = DIR_CW;
		stepsToMove = 0;
		outputCurrent = 500;

		HAL_GPIO_WritePin(pinPorts[2],  controlPins[2], GPIO_PIN_RESET);
		HAL_GPIO_WritePin(pinPorts[3],  controlPins[3], GPIO_PIN_SET);
	}
};

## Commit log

2023-01-29 initial project upload
    [CockpitIOPlugin.obj, Hello-World-SDK-3.obj, hid.obj]
2023-01-29 added PCB design
    [PlaneSimulatorIO.brd, PlaneSimulatorIO.sch]

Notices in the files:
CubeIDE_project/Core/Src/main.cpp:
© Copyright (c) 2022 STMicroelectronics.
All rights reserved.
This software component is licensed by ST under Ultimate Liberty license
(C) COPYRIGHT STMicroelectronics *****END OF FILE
